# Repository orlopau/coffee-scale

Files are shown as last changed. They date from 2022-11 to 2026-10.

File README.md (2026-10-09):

# Coffee-Scale




---

This project contains the schematics, code and 3D models for a coffee scale based on an ESP32.

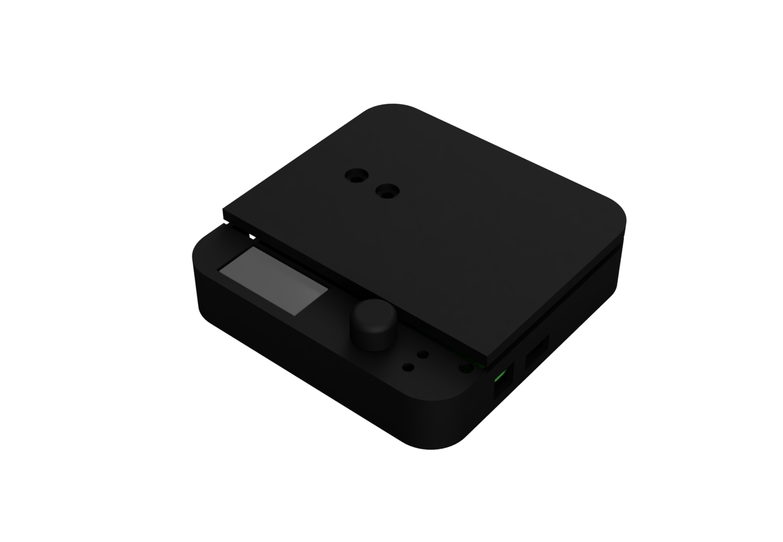
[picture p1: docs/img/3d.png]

 
## Features
* OTA updates via WiFi
* Recipe-based brewing
* Auto averaging of weight values: more values are used to determine weight when weight is relatively constant
* Brew timer
* USB-C charging
* Interchangeable Load Cell
* 3D-printable case
* Bluetooth and Wi-Fi connectivity

## Recipe-Based Brewing
The scale can be used to brew coffee using a step-by-step recipe. 
The recipe is stored on the scale, and can be adjusted while brewing.

Possible adjustments include:
- Changing the amount of coffee
- Changing the brew ratio
- Other adjustments based on the chosen recipe

## Development: Updating From Your Computer
During development, the scale can install a build straight from your computer over Wi-Fi, without USB and without a GitHub release.

1. In `code/`, run `pio run -t serve`. This builds the firmware and serves it on your network. It is found by the scale via mDNS, so your computer's IP does not matter. The first run installs the Python package `zeroconf`.
2. Hold the button while switching on the scale to open the updater. It connects to the Wi-Fi saved in the updater.
3. On the language screen, **long-press** the button instead of clicking. The scale searches for your computer and installs the build.

The server keeps running, so for the next build repeat steps 2 and 3 (`pio run -t serve` rebuilds when restarted). If the scale already runs the served build, it shows "No update available". Your computer and the scale must be on the same network, and the firewall must allow incoming connections for the server.

## Development: Emulator
The emulator runs the firmware on your computer, in a window that shows the scale's display. It needs SDL2 (`sudo apt install libsdl2-dev` on Debian/Ubuntu).

```
cd code
pio run -e emulator -t exec
```

With `COMPILE_LANG=de` in front, it runs in German. The load cell is simulated, and the keyboard replaces the encoder:

| Key | Action |
|---|---|
| Left / Right | turn the encoder |
| Enter, Space | press the encoder, hold for a long press |
| Up / Down | put 1 g on the scale or take it off, with Shift 0.1 g |
| PageUp / PageDown | 10 g on or off |
| Home | 100 g, e.g. for the calibration |
| 0, Backspace | clear the scale |
| F | pour on/off, 2 g/s |
| S | espresso shot: 6 s pre-infusion, then about 38 g in 33 s |
| N | noise on/off |
| - / + | slower/faster time, up to 20x (1x while the button is held) |
| P | save a screenshot to the current directory |
| Esc, Q | quit |

The window title shows the weight on the scale. The frame around the display lights up while the buzzer sounds. Settings are kept in memory only, and the boot splash screen and the updater only run on the device.

## Development: Screenshot Tests
The native tests render every screen through u8g2, set up like the scale's display, and compare it with the reference images in `code/test/native/test_screenshots/screens/`. A screen that changes fails the tests, and its new image is written to `code/test/native/test_screenshots/failed/` (on GitHub, attached to the CI run as `failed-screenshots`).

After changing a screen on purpose, accept the new images and commit them with the change:

```
cd code
UPDATE_SCREENSHOTS=1 pio test -e native -f native/test_screenshots
```

The diff of the pull request then shows each changed screen before and after.

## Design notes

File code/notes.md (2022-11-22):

## Modules

* Display/Output
* RotaryEncoder/Input
* LoadCell
* Modes...

soldering k12
https://www.aliexpress.com/item/4000456148198.html?spm=a2g0o.cart.0.0.4b184ae4xzGph2&mp=1

tips:
D32, D24, D16, D12, KF, ILS

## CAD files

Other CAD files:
models/Knob.step
models/Scale.step

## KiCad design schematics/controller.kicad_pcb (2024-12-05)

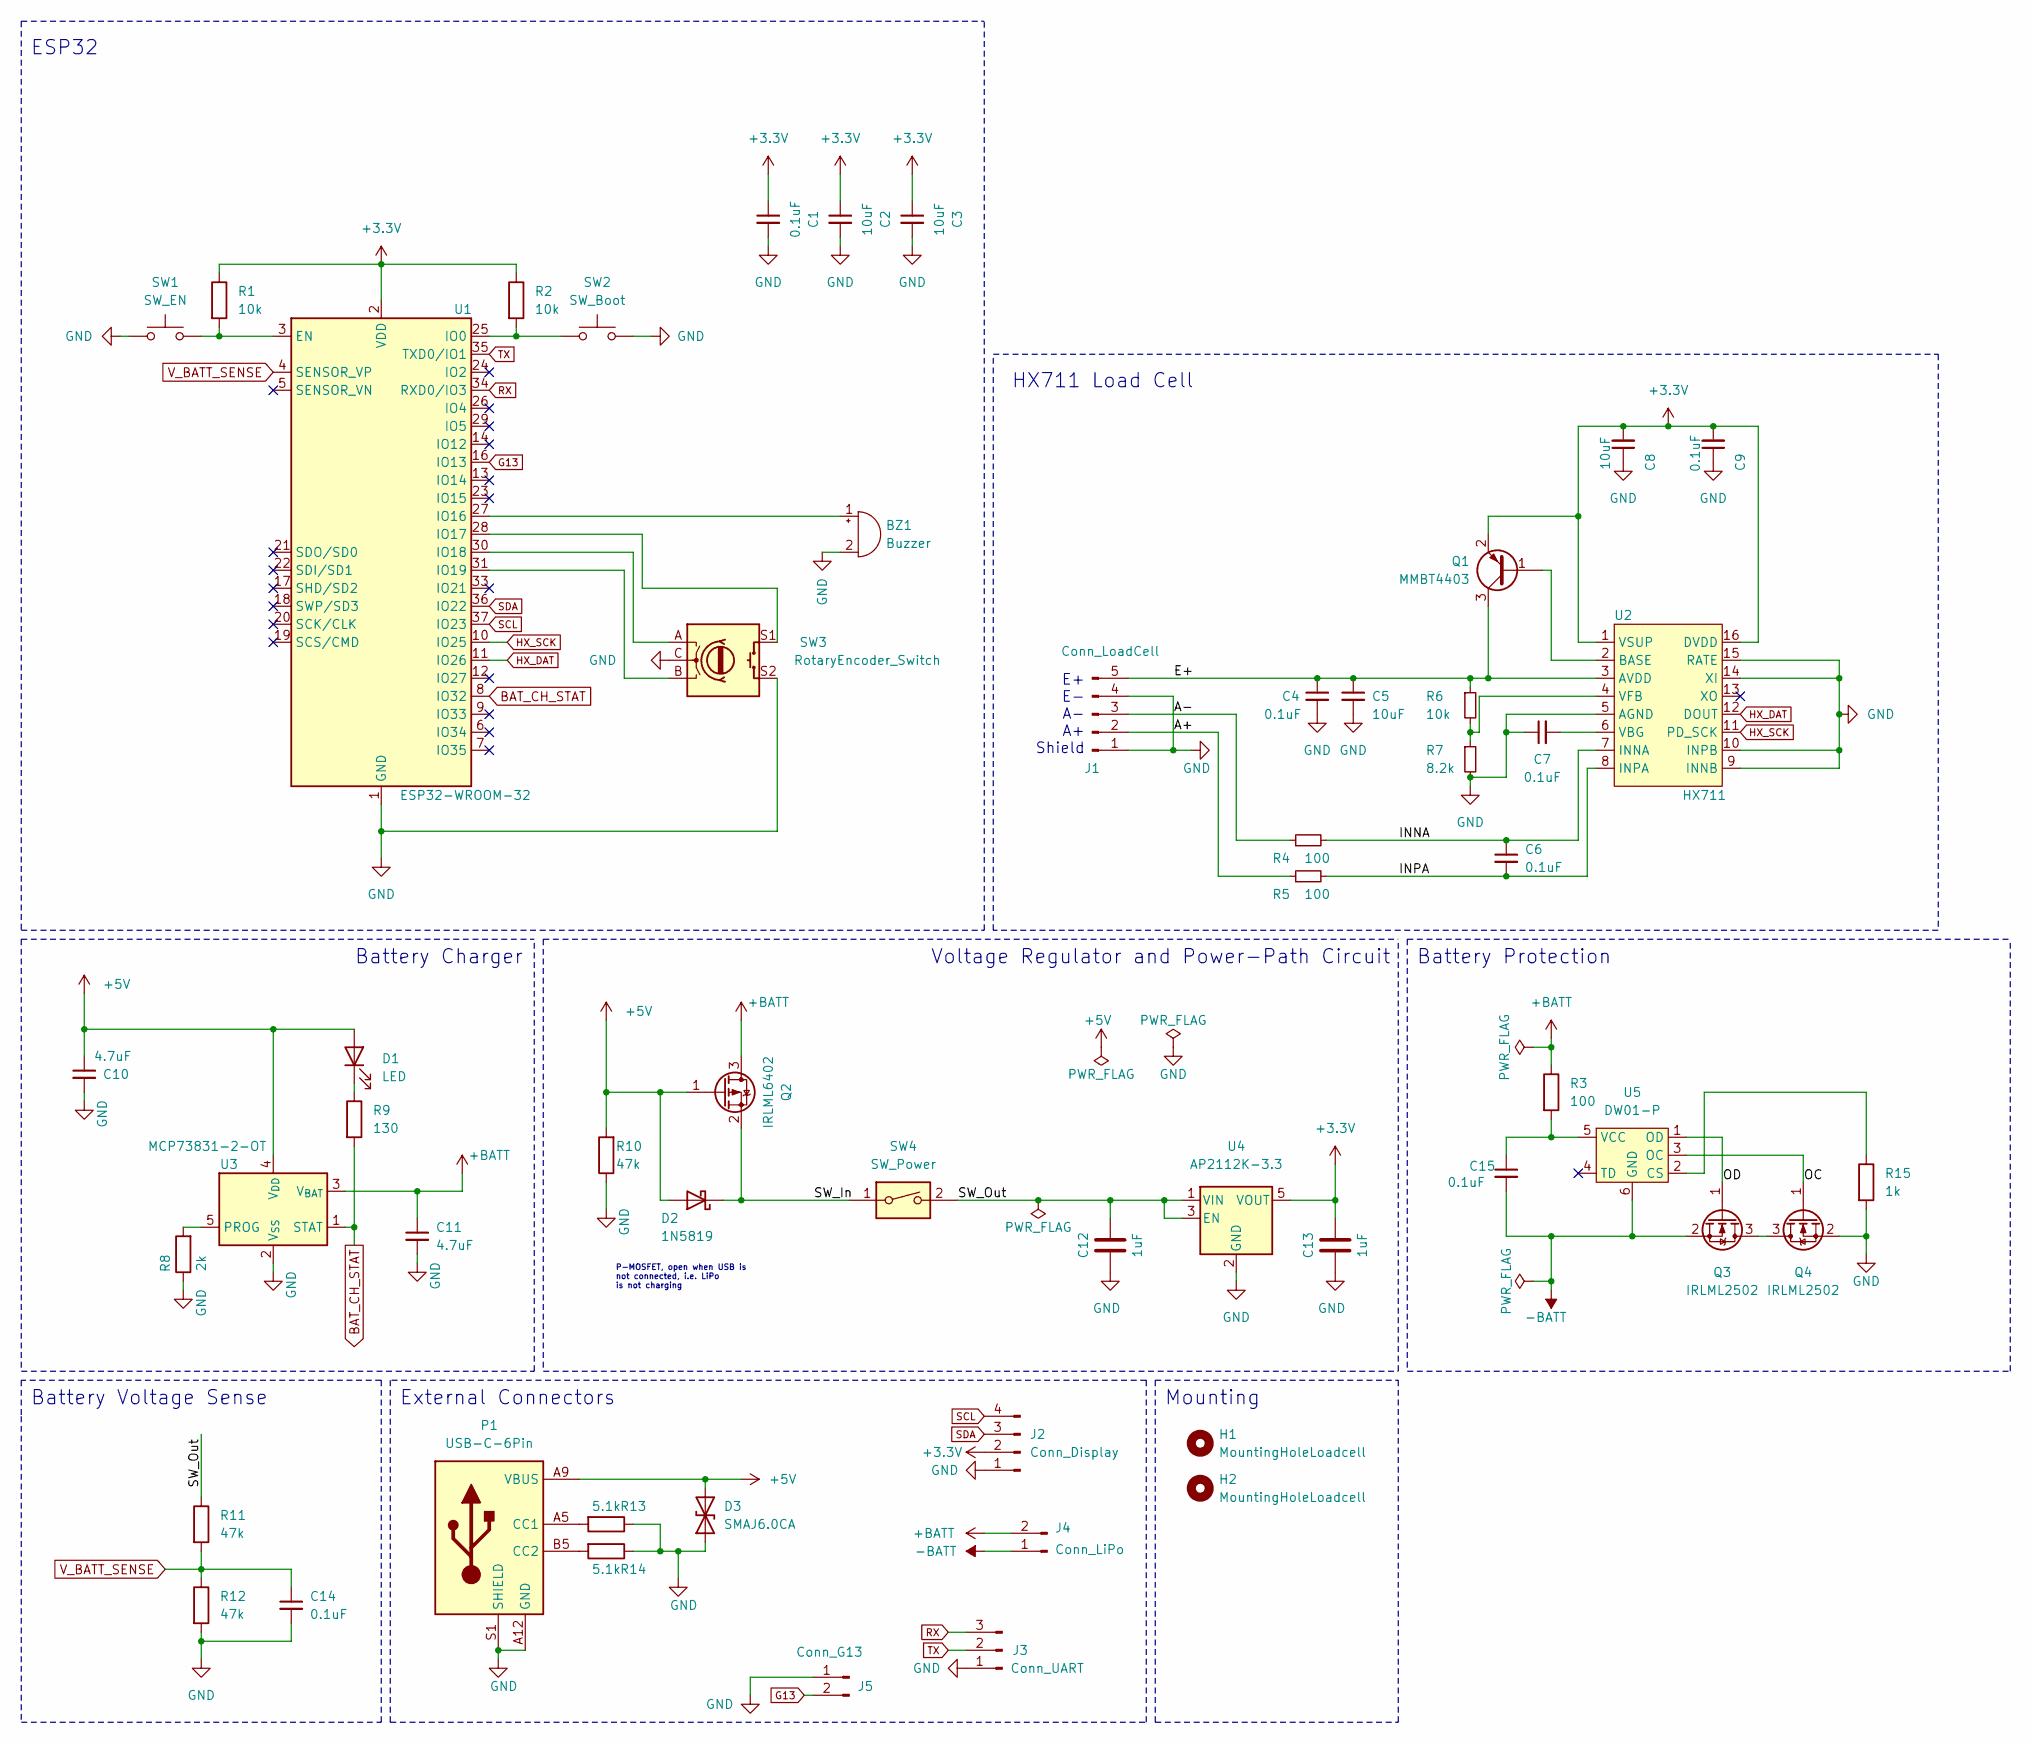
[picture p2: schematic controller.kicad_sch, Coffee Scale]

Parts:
BZ1: Buzzer; Buzzer_12x9.5RM7.6
C1, C4, C6, C7, C9, C14, C15: 0.1uF; C_0603_1608Metric_Pad1.08x0.95mm_HandSolder; LCSC C14663
C2, C3, C5, C8: 10uF; C_1206_3216Metric; LCSC C13585
C10, C11: 4.7uF; C_0805_2012Metric; LCSC C1779
C12, C13: 1uF; C_0805_2012Metric; LCSC C28323
D1: LED; LED_1206_3216Metric; LCSC C125086
D2: 1N5819; D_SMA_Handsoldering
D3: SMAJ6.0CA; D_SMA
H1, H2: MountingHoleLoadcell; MountingHole_5.3mm_M5_ISO7380
J1: Conn_LoadCell; SolderWire-0.5sqmm_1x05_P4.8mm_D0.9mm_OD2.3mm
J2: Conn_Display; SolderWire-0.5sqmm_1x04_P4.8mm_D0.9mm_OD2.3mm
J3: Conn_UART; PinHeader_1x03_P2.54mm_Horizontal
J4: Conn_LiPo; SolderWire-0.5sqmm_1x02_P4.8mm_D0.9mm_OD2.3mm
J5: Conn_G13; SolderWire-0.5sqmm_1x02_P4.8mm_D0.9mm_OD2.3mm
P1: USB-C-6Pin; USB_C_6Pin
Q1: MMBT4403; SOT-23; LCSC C78864
Q2: IRLML6402; SOT-23; LCSC C2593
Q3, Q4: IRLML2502; SOT-23; LCSC C5364308
R1, R2, R6: 10k; R_0603_1608Metric_Pad0.98x0.95mm_HandSolder; LCSC C25804
R3, R4, R5: 100; R_0603_1608Metric_Pad0.98x0.95mm_HandSolder; LCSC C22775
R7: 8.2k; R_0603_1608Metric_Pad0.98x0.95mm_HandSolder; LCSC C25981
R8: 2k; R_0603_1608Metric_Pad0.98x0.95mm_HandSolder; LCSC C22975
R9: 130; R_0603_1608Metric_Pad0.98x0.95mm_HandSolder; LCSC C22808
R10, R11, R12: 47k; R_0603_1608Metric_Pad0.98x0.95mm_HandSolder; LCSC C25819
R13, R14: 5.1k; R_0603_1608Metric_Pad0.98x0.95mm_HandSolder; LCSC C23186
R15: 1k; R_0603_1608Metric_Pad0.98x0.95mm_HandSolder; LCSC C21190
SW1: SW_EN; SW_PUSH_6mm_H5mm
SW2: SW_Boot; SW_PUSH_6mm_H5mm
SW3: RotaryEncoder_Switch; RotaryEncoder_Alps_EC11E-Switch_Vertical_H20mm
SW4: SW_Power; SolderWire-0.5sqmm_1x02_P4.8mm_D0.9mm_OD2.3mm
U1: ESP32-WROOM-32; LCSC C473012
U2: HX711; SOP-16_3.9x9.9mm_P1.27mm; LCSC C6705483
U3: MCP73831-2-OT; SOT-23-5; LCSC C424093
U4: AP2112K-3.3; SOT-23-5; LCSC C51118
U5: DW01-P; SOT-23-6_Handsoldering; LCSC C18164398

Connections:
+3.3V: C1.1, C2.1, C3.1, C8.2, C9.2, C13.2, J2.2, Q1.2 (E), R1.1, R2.1, U1.2 (VDD), U2.1 (VSUP), U2.16 (DVDD), U4.5 (VOUT)
+5V: C10.1, D1.2 (A), D2.2 (A), D3.2 (A2), P1.A9 (VBUS), P1.B9 (VBUS), Q2.1 (G), R10.2, U3.4 (V_{DD})
+BATT: C11.1, J4.2, Q2.3 (D), R3.1, U3.3 (V_{BAT})
-BATT: C15.2, J4.1, Q3.2 (S), U5.6 (GND)
/E+: C4.1, C5.1, J1.5, Q1.3 (C), R6.1, U2.3 (AVDD)
/INNA: C6.1, R4.2, U2.7 (INNA)
/INPA: C6.2, R5.2, U2.8 (INPA)
/OC: Q4.1 (G), U5.3 (OC)
/OD: Q3.1 (G), U5.1 (OD)
/SW_In: D2.1 (K), Q2.2 (S), SW4.1
/SW_Out: C12.2, R11.1, SW4.2, U4.1 (VIN), U4.3 (EN)
BAT_CH_STAT: R9.2, U1.8 (IO32), U3.1 (STAT)
G13: J5.2, U1.16 (IO13)
HX_DAT: U1.11 (IO26), U2.12 (DOUT)
HX_SCK: U1.10 (IO25), U2.11 (PD_SCK)
unnamed: BZ1.1 (+), U1.27 (IO16)
unnamed: D1.1 (K), R9.1
unnamed: P1.A5 (CC1), R13.2
unnamed: P1.B5 (CC2), R14.2
unnamed: Q1.1 (B), U2.2 (BASE)
unnamed: Q3.3 (D), Q4.3 (D)
unnamed: R1.2, SW1.2, U1.3 (EN)
unnamed: R2.2, SW2.1, U1.25 (IO0)
unnamed: SW3.S1, U1.28 (IO17)
unnamed: SW3.A, U1.30 (IO18)
unnamed: SW3.B, U1.31 (IO19)
unnamed: C7.2, U2.6 (VBG)
unnamed: R6.2, R7.1, U2.4 (VFB)
unnamed: R8.2, U3.5 (PROG)
unnamed: R15.1, U5.2 (CS)
unnamed: C15.1, R3.2, U5.5 (VCC)
RX: J3.3, U1.34 (RXD0/IO3)
SCL: J2.4, U1.37 (IO23)
SDA: J2.3, U1.36 (IO22)
TX: J3.2, U1.35 (TXD0/IO1)
V_BATT_SENSE: C14.1, R11.2, R12.1, U1.4 (SENSOR_VP)

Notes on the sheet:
ESP32
Battery Charger
HX711 Load Cell
E+ E- A- A+ Shield
Battery Protection
Mounting
External Connectors
Battery Voltage Sense
Voltage Regulator and Power-Path Circuit
P-MOSFET, open when USB is not connected, i.e. LiPo is not charging

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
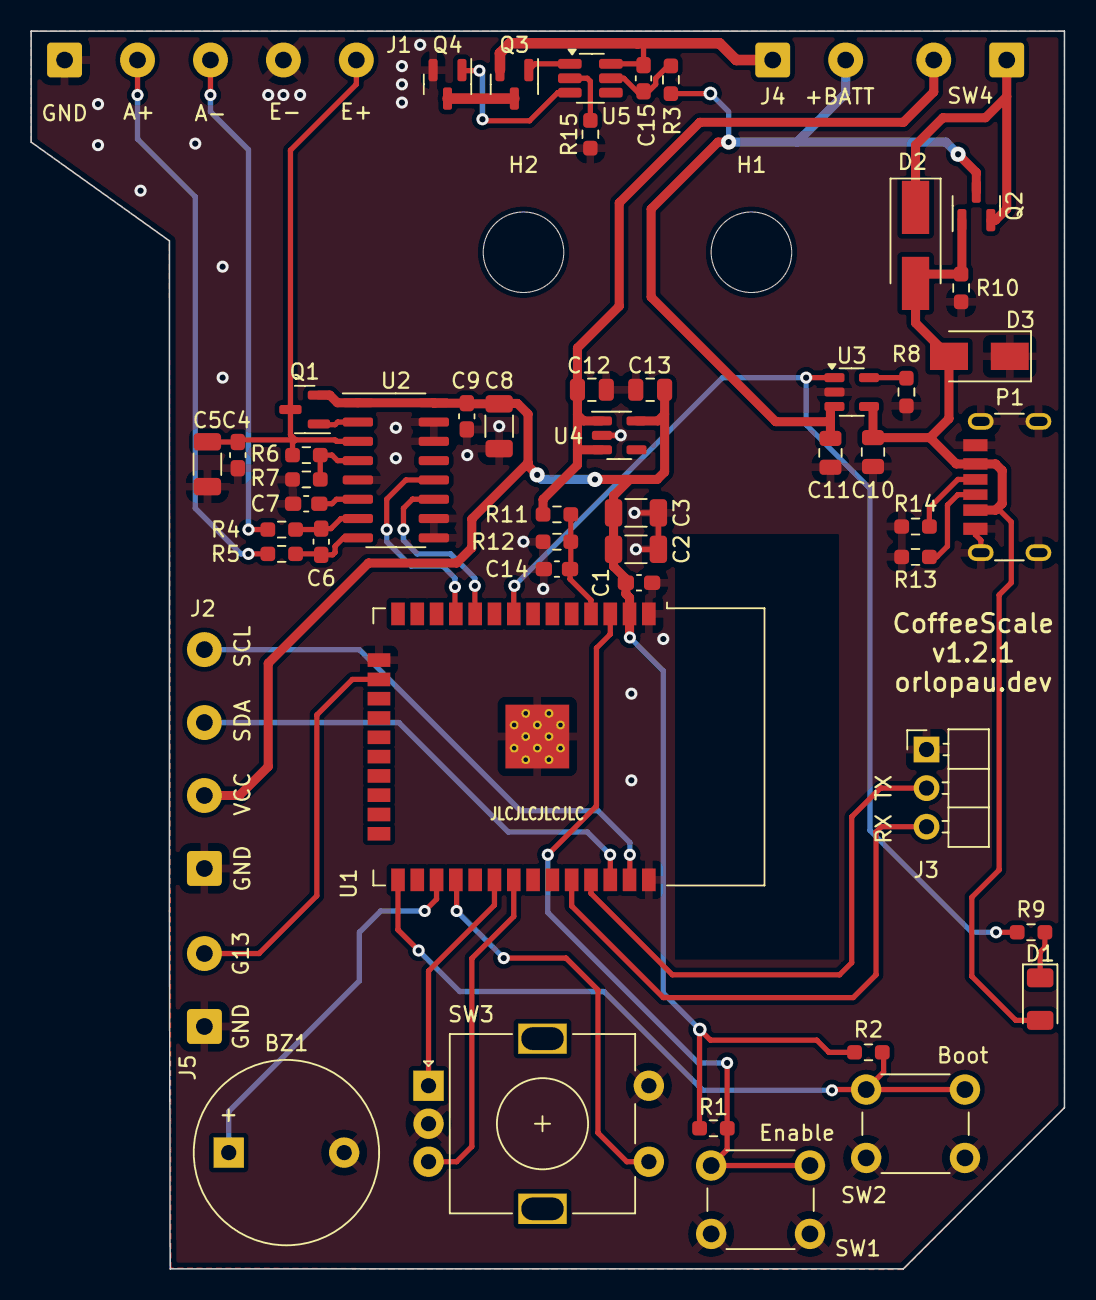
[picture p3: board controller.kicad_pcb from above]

Board: 2 copper layers, 68.0 x 81.5 mm, 55 parts (0 on the bottom side), 39 nets.

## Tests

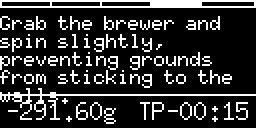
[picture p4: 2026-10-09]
code/test/native/test_screenshots/screens/recipe_brewing_3_pour_3.png

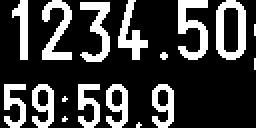
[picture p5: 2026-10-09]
code/test/native/test_screenshots/screens/scale_big.png

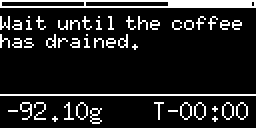
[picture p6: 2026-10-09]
code/test/native/test_screenshots/screens/recipe_brewing_4_pour_2.png

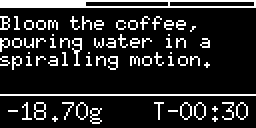
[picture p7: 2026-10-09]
code/test/native/test_screenshots/screens/recipe_brewing_4_pour_0.png

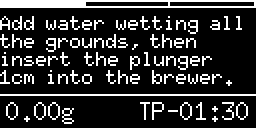
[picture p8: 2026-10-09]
code/test/native/test_screenshots/screens/recipe_brewing_pause.png

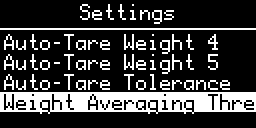
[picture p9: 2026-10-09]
code/test/native/test_screenshots/screens/settings_last.png

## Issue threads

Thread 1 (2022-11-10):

Buzzer is very quiet

orlopau, 2022-11-10:
Additional MOSFET to switch buzzer?
Use lower R value?

Closed 2022-12-08.

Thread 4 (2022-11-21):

PCB improvements

orlopau, 2022-11-21:
- [x] Add battery protection ic (S-8240A, DW01, AP9101C)
- [x] Add TVS diode
- [x] Add LiIon fuel gauge IC (discarded due to no availability of parts)
- [x] Add automatic boot mode change (automatic upload) (discarded, too many external pins)
- [x] Add RTS pin to pin header (see above)
- [x] Replace buzzer footprint
- [x] Tighter screw holes
- [x] More accessible buttons
- [ ] Route out GPIO pins (?) for later additions
- [ ] Realign Boot BTN with Rotary Encoder center

Closed 2022-12-14.

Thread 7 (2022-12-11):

Replaceable LiIon Battery

orlopau, 2022-12-11:

Closed 2023-01-05.

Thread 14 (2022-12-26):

AP9101 not auto-waking

orlopau, 2022-12-26:
After over-discharge protection triggers, bat GND and GND muste be shorted to activate the chip again. There is also an auto-wakeup version of this chip available.

orlopau, 2023-05-06:
Quickfix: Add a button to reset the chip? Maybe the exposed boot button can be used, or rotary encoder button?

orlopau, 2024-12-14:
Fixed in new HW revision pcb-v1.2.1

Closed 2024-12-14.

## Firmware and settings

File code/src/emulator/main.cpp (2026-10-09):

#ifdef EMULATOR

// The scale's firmware on a computer: runs the modes like on the device, in
// a window, with the keyboard as encoder and a simulated load cell.
//
//   pio run -e emulator -t exec

#define SDL_MAIN_HANDLED
#include <SDL.h>

#include <cstdio>
#include <fstream>
#include <string>

#include "emulator/emulator.h"
#include "battery.h"
#include "data/recipes.h"
#include "display.h"
#include "interface.h"
#include "loadcell.h"
#include "millis.h"
#include "mode_manager.h"
#include "modes/mode_calibrate.h"
#include "modes/mode_espresso.h"
#include "modes/mode_recipe.h"
#include "modes/mode_scale.h"
#include "modes/mode_settings.h"
#include "settings.h"
#include "stopwatch.h"
#include "weight_sensor.h"

// window pixels per display pixel, and the frame around the display
#define PIXEL_SIZE 4
#define BORDER 12
#define FRAME_MS 15
// liquid flowing onto the scale while pouring, in g/s
#define POUR_FLOW 2.0f

static const int SPEEDS[] = {1, 2, 5, 10, 20};
static const int SPEED_COUNT = sizeof(SPEEDS) / sizeof(SPEEDS[0]);

static const char *HELP = "Coffee Scale emulator\n"
                          "  Left/Right       turn the encoder\n"
                          "  Enter, Space     press the encoder (hold for a long press)\n"
                          "  Up/Down          put 1 g on the scale or take it off, with Shift 0.1 g\n"
                          "  PageUp/PageDown  10 g, Home 100 g (e.g. for calibration)\n"
                          "  0, Backspace     clear the scale\n"
                          "  F                pour on/off (2 g/s)\n"
                          "  S                espresso shot (6 s pre-infusion, about 38 g in 33 s)\n"
                          "  N                noise on/off\n"
                          "  - +              slower/faster time, up to 20x (1x while the button is held)\n"
                          "  P                save a screenshot\n"
                          "  Esc, Q           quit\n";

static DefaultWeightSensor weightSensor;
static Stopwatch stopwatch;

static void saveScale(float scale)
{
    printf("New scale: %f\n", scale);
    weightSensor.setScale(scale);
}

/** As the device's setup() does, with the scale calibrated already. */
static void setup()
{
    Interface::begin();
    Battery::init();
    Display::begin();
    weightSensor.begin();

    const float scale = 1 / SimulatedScale::COUNTS_PER_GRAM;
    weightSensor.setScale(scale);
    const float delta = fabs(Settings::getFloat(Settings::floatSettings[Settings::AVERAGING_DELTA]) / scale);
    weightSensor.setAutoAveraging(delta, 64);

    // tare after 32 samples
    for (int i = 0; i < 32;)
    {
        sleep_for(1);
        weightSensor.update();
        if (weightSensor.isNewWeight())
        {
            i++;
        }
    }
    weightSensor.tare();
}

/** One pass of the device's loop(). */
static void loop(ModeManager &modeManager)
{
    Interface::update();
    weightSensor.update();
    modeManager.update();
}

static void saveScreenshot()
{
    static int count = 0;
    std::string path;
    // the next free name, so earlier screenshots are kept
    do
    {
        path = "screenshot-" + std::to_string(++count) + ".png";
    } while (std::ifstream(path).good());
    std::ofstream(path, std::ios::binary) << Emulator::display().png(PIXEL_SIZE);
    printf("Saved %s\n", path.c_str());
}

static void updateTitle(SDL_Window *window, int speed)
{
    char title[128];
    int length = snprintf(title, sizeof(title), "Coffee Scale - %.1f g on the scale", Emulator::scale.getWeight());
    if (Emulator::scale.isShotRunning())
    {
        length += snprintf(title + length, sizeof(title) - length, " - shot, %.1f g/s", Emulator::scale.getFlow());
    }
    else if (Emulator::scale.getFlow() != 0)
    {
        length += snprintf(title + length, sizeof(title) - length, " - pouring %.1f g/s", Emulator::scale.getFlow());
    }
    if (Emulator::scale.hasNoise())
    {
        length += snprintf(title + length, sizeof(title) - length, " - noise");
    }
    if (speed != 1)
    {
        snprintf(title + length, sizeof(title) - length, " - %dx", speed);
    }

    static std::string shown;
    if (shown != title)
    {
        SDL_SetWindowTitle(window, title);
        shown = title;
    }
}

static void draw(SDL_Renderer *renderer, SDL_Texture *texture)
{
    VirtualDisplay &display = Emulator::display();
    uint32_t *pixels;
    int pitch;
    SDL_LockTexture(texture, nullptr, (void **)&pixels, &pitch);
    for (int y = 0; y < display.height(); y++)
    {
        for (int x = 0; x < display.width(); x++)
        {
            pixels[y * pitch / 4 + x] = display.pixel(x, y) ? 0xFFE8F0FF : 0xFF000000;
        }
    }
    SDL_UnlockTexture(texture);

    // the frame lights up while the buzzer sounds
    if (Emulator::isBuzzing())
    {
        SDL_SetRenderDrawColor(renderer, 0xF0, 0xA0, 0x20, 0xFF);
    }
    else
    {
        SDL_SetRenderDrawColor(renderer, 0x30, 0x30, 0x30, 0xFF);
    }
    SDL_RenderClear(renderer);
    const SDL_Rect screen = {BORDER, BORDER, display.width() * PIXEL_SIZE, display.height() * PIXEL_SIZE};
    SDL_RenderCopy(renderer, texture, nullptr, &screen);
    SDL_RenderPresent(renderer);
}

/** Handles a key, returns false to quit. */
static bool handleKey(const SDL_KeyboardEvent &key, int &speedIndex)
{
    const bool down = key.type == SDL_KEYDOWN;
    const bool shift = key.keysym.mod & KMOD_SHIFT;
    SimulatedScale &scale = Emulator::scale;

    switch (key.keysym.sym)
    {
    case SDLK_RETURN:
    case SDLK_KP_ENTER:
    case SDLK_SPACE:
        Emulator::setButtonPressed(down);
        return true;
    case SDLK_ESCAPE:
    case SDLK_q:
        return !down;
    }

    if (!down)
    {
        return true;
    }

    // keys that may repeat while held
    switch (key.keysym.sym)
    {
    case SDLK_RIGHT:
        Emulator::turnEncoder(1);
        break;
    case SDLK_LEFT:
        Emulator::turnEncoder(-1);
        break;
    case SDLK_UP:
        scale.addWeight(shift ? 0.1f : 1);
        break;
    case SDLK_DOWN:
        scale.addWeight(shift ? -0.1f : -1);
        break;
    case SDLK_PAGEUP:
        scale.addWeight(10);
        break;
    case SDLK_PAGEDOWN:
        scale.addWeight(-10);
        break;
    case SDLK_HOME:
        scale.addWeight(100);
        break;
    }

    if (key.repeat)
    {
        return true;
    }

    switch (key.keysym.sym)
    {
    case SDLK_0:
    case SDLK_KP_0:
    case SDLK_BACKSPACE:
        scale.setWeight(0);
        break;
    case SDLK_f:
        scale.setFlow(scale.getFlow() == 0 || scale.isShotRunning() ? POUR_FLOW : 0);
        break;
    case SDLK_s:
        scale.startShot();
        break;
    case SDLK_n:
        scale.setNoise(!scale.hasNoise());
        break;
    case SDLK_MINUS:
    case SDLK_KP_MINUS:
        speedIndex = speedIndex > 0 ? speedIndex - 1 : 0;
        break;
    case SDLK_PLUS:
    case SDLK_EQUALS: // + without Shift on US keyboards
    case SDLK_KP_PLUS:
        speedIndex = speedIndex < SPEED_COUNT - 1 ? speedIndex + 1 : SPEED_COUNT - 1;
        break;
    case SDLK_p:
        saveScreenshot();
        break;
    }
    return true;
}

int main(int argc, char **argv)
{
    // line by line, also when the output goes to a pipe, e.g. with pio run -t exec
    setvbuf(stdout, nullptr, _IOLBF, 0);
    setup();

    ModeScale modeDefault(weightSensor, stopwatch);
    ModeEspresso modeEspresso(weightSensor, stopwatch);
    ModeCalibration modeCalibration(stopwatch, saveScale);
    ModeSettings modeSettings;
    ModeRecipes modeRecipes(weightSensor, RECIPES, RECIPE_COUNT);
    Mode *modes[] = {&modeDefault, &modeRecipes, &modeEspresso, &modeCalibration, &modeSettings};
    ModeManager modeManager(modes, 5, Display::canvas());
    modeManager.begin();

    SDL_SetMainReady();
    if (SDL_Init(SDL_INIT_VIDEO) != 0)
    {
        fprintf(stderr, "SDL_Init failed: %s\n", SDL_GetError());
        return 1;
    }
    VirtualDisplay &display = Emulator::display();
    SDL_Window *window = SDL_CreateWindow("Coffee Scale", SDL_WINDOWPOS_CENTERED, SDL_WINDOWPOS_CENTERED,
                                          display.width() * PIXEL_SIZE + 2 * BORDER,
                                          display.height() * PIXEL_SIZE + 2 * BORDER, 0);
    SDL_Renderer *renderer = window ? SDL_CreateRenderer(window, -1, 0) : nullptr;
    SDL_Texture *texture = renderer ? SDL_CreateTexture(renderer, SDL_PIXELFORMAT_ARGB8888, SDL_TEXTUREACCESS_STREAMING,
                                                        display.width(), display.height())
                                    : nullptr;
    if (texture == nullptr)
    {
        fprintf(stderr, "Creating the window failed: %s\n", SDL_GetError());
        return 1;
    }
    printf("%s", HELP);

    int speedIndex = 0;
    Uint64 lastRealTime = SDL_GetTicks64();
    Uint64 pendingMs = 0;
    bool running = true;
    while (running)
    {
        SDL_Event event;
        while (running && SDL_PollEvent(&event))
        {
            if (event.type == SDL_QUIT)
            {
                running = false;
            }
            else if (event.type == SDL_KEYDOWN || event.type == SDL_KEYUP)
            {
                running = handleKey(event.key, speedIndex);
            }
        }

        // The virtual clock catches up with real time, times the speed, in
        // steps of 1 ms. While the button is held, time runs at normal speed,
        // so a long press takes as long as on the device.
        const Uint64 realTime = SDL_GetTicks64();
        const Uint64 elapsed = SDL_min(realTime - lastRealTime, 100); // e.g. after the window was dragged
        lastRealTime = realTime;
        const int speed = Emulator::isButtonPressed() ? 1 : SPEEDS[speedIndex];
        pendingMs += elapsed * speed;
        for (; pendingMs > 0; pendingMs--)
        {
            sleep_for(1);
            Emulator::scale.update();
            loop(modeManager);
        }

        updateTitle(window, SPEEDS[speedIndex]);
        draw(renderer, texture);
        SDL_Delay(FRAME_MS);
    }

    SDL_DestroyTexture(texture);
    SDL_DestroyRenderer(renderer);
    SDL_DestroyWindow(window);
    SDL_Quit();
    return 0;
}

#endif

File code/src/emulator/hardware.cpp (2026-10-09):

#ifdef EMULATOR

#include <array>
#include <cmath>

#include "emulator/emulator.h"
#include "battery.h"
#include "button.h"
#include "display.h"
#include "interface.h"
#include "loadcell.h"
#include "millis.h"
#include "settings.h"

// A click shorter than the button's debounce time would get lost, e.g. when
// a key is pressed and released between two loops.
#define MIN_PRESS_MS 100

namespace Emulator
{
    SimulatedScale scale;

    static long encoderPosition = 0;
    static bool buttonDown = false;
    static unsigned long pressTime = 0;
    static Button encoderButton;
    static unsigned long buzzerEndTime = 0;

    void turnEncoder(int detents) { encoderPosition += detents; }

    void setButtonPressed(bool pressed)
    {
        if (pressed && !buttonDown)
        {
            pressTime = now();
        }
        buttonDown = pressed;
    }

    bool isButtonPressed() { return buttonDown || now() - pressTime < MIN_PRESS_MS; }

    bool isBuzzing() { return now() < buzzerEndTime; }

    VirtualDisplay &display()
    {
        static VirtualDisplay display;
        return display;
    }
}

namespace Interface
{
    // like the RotaryEncoder library: the direction since the last call
    static long lastDirectionPosition = 0;

    void begin() {}

    void update() { Emulator::encoderButton.update(Emulator::isButtonPressed()); }

    EncoderDirection getEncoderDirection()
    {
        const long position = Emulator::encoderPosition;
        const long last = lastDirectionPosition;
        lastDirectionPosition = position;
        if (position > last)
        {
            return EncoderDirection::CW;
        }
        if (position < last)
        {
            return EncoderDirection::CCW;
        }
        return EncoderDirection::NONE;
    }

    long getEncoderTicks() { return Emulator::encoderPosition; }

    void setEncoderTicks(long ticks) { Emulator::encoderPosition = ticks; }

    void resetEncoderTicks() { Emulator::encoderPosition = 0; }

    ClickType consumeEncoderClick() { return Emulator::encoderButton.consumeClickType(); }

    ClickType getEncoderClick() { return Emulator::encoderButton.getClickType(); }

    bool isEncoderPressed() { return Emulator::encoderButton.isPressed(); }

    void buzzerTone(unsigned int durationMs) { Emulator::buzzerEndTime = now() + durationMs; }
}

namespace LoadCell
{
    void begin() {}

    bool isReady() { return Emulator::scale.isReady(); }

    long read() { return Emulator::scale.read(); }
}

namespace Display
{
    void begin() {}

    Canvas &canvas() { return Emulator::display().canvas(); }

    // The splash screen draws with u8g2's Arduino API, which needs the device.
    void drawOpener() {}
}

namespace Battery
{
    void init() {}

    float getVoltage() { return 3.95f; }

    float getPercentage() { return 75; }

    bool isCharging() { return false; }
}

// Kept in memory only, every start begins with the defaults.
namespace Settings
{
    static std::array<float, FLOAT_SETTING_NUM> values = [] {
        std::array<float, FLOAT_SETTING_NUM> v;
        v.fill(NAN);
        return v;
    }();

    float getFloat(FloatSetting s) { return std::isnan(values[s.id]) ? s.def : values[s.id]; }

    void setFloat(FloatSetting s, float value) { values[s.id] = value; }

    void commit() {}
}

#endif

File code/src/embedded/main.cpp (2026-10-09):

#if !defined(PIO_UNIT_TESTING) && !defined(NATIVE)

#include <Arduino.h>
#include <EEPROM.h>

#include "constants.h"
#include "data/recipes.h"
#include "loadcell.h"
#include "mode.h"
#include "mode_manager.h"
#include "modes/mode_scale.h"
#include "modes/mode_espresso.h"
#include "modes/mode_calibrate.h"
#include "modes/mode_recipe.h"
#include "modes/mode_settings.h"
#include "display.h"
#include "update.h"
#include "interface.h"
#include "battery.h"

#define AVERAGING_LOOPS 100

#define TAG "MAIN"

DefaultWeightSensor weightSensor;
Stopwatch stopwatch;

void saveScale(float scale)
{
  ESP_LOGI(TAG, "New scale: %f", scale);
  ESP_LOGI(TAG, "Saving scale to EEPROM...");
  EEPROM.put(EEPROM_ADDR_SCALE, scale);
  EEPROM.commit();
  weightSensor.setScale(scale);
}

ModeScale modeDefault(weightSensor, stopwatch);
ModeEspresso modeEspresso(weightSensor, stopwatch);
ModeCalibration modeCalibration(stopwatch, saveScale);
ModeSettings modeSettings;
ModeRecipes modeRecipes(weightSensor, RECIPES, RECIPE_COUNT);
Mode *modes[] = {&modeDefault, &modeRecipes, &modeEspresso, &modeCalibration, &modeSettings};
ModeManager modeManager(modes, 5, Display::canvas());

Interface::EncoderDirection encoderDirection;

void IRAM_ATTR isr_input()
{
  Interface::update();
}

void setup()
{
  Serial.begin(115200);
  ESP_LOGI(TAG, "CoffeeScale starting up...");

  EEPROM.begin(2048);
  btStop();

  //////// INTERFACE //////
  Interface::begin();

  //////// BATTERY ////////
  Battery::init();

  //////// DISPLAY ////////
  Display::begin();
  Display::drawOpener();

  //////// WEIGHT SENSOR ////////
  LoadCell::begin();
  weightSensor.begin();

  float scale;
  EEPROM.get(EEPROM_ADDR_SCALE, scale);
  if (isnan(scale))
  {
      scale = 1.0f;
  }

  ESP_LOGI(TAG, "Existing scale: %f", scale);
  weightSensor.setScale(scale);


  float delta = abs(Settings::getFloat(Settings::floatSettings[Settings::AVERAGING_DELTA]) / scale);
  weightSensor.setAutoAveraging(delta, 64);
  ESP_LOGI(TAG, "Auto averaging delta: %f", delta);

  // tare after 32 samples
  ESP_LOGI(TAG, "Taring...");
  for (int i = 0; i < 32;)
  {
      weightSensor.update();
      if (weightSensor.isNewWeight())
      {
          i++;
      }
  }
  weightSensor.tare();
  ESP_LOGI(TAG, "Tared!");

  //////// INTERRUPTS ////////
  attachInterrupt(PIN_ENC_A, isr_input, CHANGE);
  attachInterrupt(PIN_ENC_B, isr_input, CHANGE);
  attachInterrupt(PIN_ENC_BTN, isr_input, CHANGE);

  //////// UPDATES ////////
  if (digitalRead(PIN_UPDATE_FIRMWARE) == LOW)
  {
      Updater::update_firmware();
  }

  /// MODE MANAGER ////
  modeManager.begin();

  ESP_LOGI(TAG, "Setup finished!");
}

#ifdef PERF
unsigned int loops = 0;
unsigned long lastTime = millis();
#endif

void loop()
{
  Interface::update();
  weightSensor.update();
  modeManager.update();

#ifdef PERF
  if (loops >= AVERAGING_LOOPS)
  {
    ESP_LOGI(TAG, "Loop time: %lu", (millis() - lastTime) / loops);
    loops = 0;
    lastTime = millis();
  }
  loops++;
#endif
}

#endif

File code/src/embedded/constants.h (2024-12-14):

#ifndef NATIVE

#pragma once

// Pin definitions
#define PIN_BOOT 0

#define PIN_I2C_SDA 22
#define PIN_I2C_SCL 23

#define PIN_BUZZER 16

#define PIN_BAT_CHARGE_STATUS 32

#define PIN_HX711_SCK 25
#define PIN_HX711_DAT 26

#define PIN_ENC_A 18
#define PIN_ENC_B 19
#define PIN_ENC_BTN 17

#define PIN_BAT_ADC 36

// Other constants
#define BAT_V_MULTIPLIER 2.0f
#define BAT_V_MIN 3.2f
#define BAT_V_MAX 4.2f

#define ADC_OFFSET 0.04f

// EEPROM addresses
#define EEPROM_ADDR_SCALE 0
#define EEPROM_ADDR_FLOAT_SETTINGS 10

// BUTTONS
#define PIN_UPDATE_FIRMWARE PIN_ENC_BTN

// UPDATE
#define UPDATE_URL "https://github.com/orlopau/coffee-scale/releases/latest/download/firmware%s.bin"

#ifndef FIRMWARE_VERSION
#define FIRMWARE_VERSION "0.0.0"
#endif

#endif

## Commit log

2022-11-02 Added pcb design
    [controller.kicad_pcb, controller.kicad_sch]
2022-11-07 Updated pcb
    [controller.kicad_pcb]
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2022-11-26 Fixed tests for mode manager and mode default
    [main.cpp]
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2022-12-01 Reworked mode switcher
2022-12-01 Fixed segfault, missing null termiantion
    [main.cpp]
2022-12-01 Fixed mode manager
    Mode manager called the update function of the next chosen mode in the same tick.
    This lead to the single click which is needed to select a new mode being propagated
    instantly to the new mode.
    [main.cpp]
2022-12-02 Updated voltage divider for hx711 in schematic
    [controller.kicad_pcb, controller.kicad_sch]
2022-12-06 Fixed ratio of pours not being adjusted
    [main.cpp]
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2022-12-06 Fixed test for loadcell tare
    Was not adjusted to taring via rotating the encoder
    [main.cpp]
2022-12-06 Added buzzer tone function
    [main.cpp]
2022-12-14 Updated schematic to v1.1.0
    * Added TVS diode for USB connector
    * Added active buzzer instead of passive piezo buzzer
    * Added battery protection IC
    * Changed location of enable button, enabling the mounting of a button which is visible externally
    [controller.kicad_pcb, controller.kicad_sch]
2022-12-14 Changed circular mounting holes to eliptical for rotary encoder
    [controller.kicad_pcb, controller.kicad_sch]
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2022-12-21 Fixed pause time not being shown when pour time is zero
    When autoStart was not disabled for a pour, and the
    pourTime for that pour was 0, 0 would be displayed instead
    of the pauseTime.
    [main.cpp]
2022-12-27 Fixed wrong scaling for ADC values
    [adc_battery.cpp, main.cpp]
2022-12-27 Fixed brewing step showing only the weight of the current pour
    [main.cpp]
2023-01-05 Fixed calibration mode
2023-01-05 Fixed unstable debounce test
    [main.cpp]
2023-01-09 Fixed update not using HTTPS
    [constants.h]
2023-01-09 Fixed calibration not waiting for laodcell readiness
    [main.cpp]
2023-01-09 Added long click detection when button is kept pressed
    Previously for detecting a long click the button must have been released.
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2023-01-10 Fixed flickering battery display by introducing an update interval
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2023-01-10 Fixed voltage not showing when internal millis was less than interval
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2023-04-03 Fixed a bug when setting a new ratio, advancing to the weight config step and then returning.
    In this case the ratio was not reset correctly.
    Closes #25.
    [main.cpp, step_config_ratio.cpp]
2023-05-06 Feature: User can force progress a pour, even when it has not finished
    Fixed #24
    [main.cpp]
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2023-05-06 Bugfix: Auto averaging did not work with negative scales
    [main.cpp]
2023-11-26 Added *.step models for scale and knob
    [Knob.step, Scale.step]
2024-12-05 Changed lipo protection IC to DW01, added LCSC part numbers
    [controller.kicad_pcb, controller.kicad_sch]
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2024-12-14 Added config parameter for auto tare tolerance
    [localization.h, main.cpp]
2026-10-09 Add Canvas abstraction, capped render loop, migrate espresso mode
    Screens no longer need to live in the Display namespace. Modes can now
    draw themselves on a small Canvas interface, and the ModeManager renders
    them at most every 50 ms instead of on every loop.
    - Canvas interface (include/canvas.h) with a u8g2 backend that only sends
    a frame over I2C when it changed (plus a refresh once per second).
    - Reusable widgets (src/ui/widgets): centered text, title line, segment
    bar, progress bar, word wrap. Legacy screens use them too and render
    pixel-identically to before.
    - Mode::render(Canvas&) / rendersToCanvas(); legacy modes keep drawing in
    update() until they are migrated.
    - Espresso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
    [main.cpp]
2026-10-09 Add dev updates from a computer via mDNS
    The firmware updater can now install a build served from the developer's
    computer instead of the latest GitHub release, for quick iteration
    without USB.
    - `pio run -t serve` builds the firmware and serves it over HTTP,
    announced via mDNS as _coffeescale-fw._tcp (scripts/serve_firmware.py,
    installs zeroconf on first use).
    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
2026-10-09 Pin the official espressif32 platform
    An unpinned `espressif32` can resolve to another installed platform of the
    same name, such as the pioarduino fork with Arduino core 3.x, which
    AutoConnect/PageBuilder do not compile against. Pin
    platformio/espressif32@7.1.3 so local builds match the release builds.
2026-10-09 Fix the German Wi-Fi setup text on the updater
    Display::text drew with drawStr, which treats text as Latin-1, so
    "wählen" showed as "wÃ¤hlen". Draw it as UTF-8 like the other screens.
    The German string also had "\v" instead of "\n" before "verbinden",
    which merged two lines and pushed text off the screen.
    [localization.h]
2026-10-09 Show the saved scale after calibration
    The result screen printed a local variable that was only set in the
    previous update(), so it showed an undefined value. Keep the scale as
    a member.
2026-10-09 Move all remaining screens into the modes' render()
    Every screen now draws through the Canvas: scale mode, all recipe steps,
    calibration, settings, the mode switcher (drawn by ModeManager) and the
    updater screens. Display keeps only begin(), canvas() and the boot
    splash. Mode::render() is now required and rendersToCanvas() is gone.
    - Canvas: fonts for the remaining screens (SmallMedium, Mono13/18/20,
    Battery) and drawGlyph() for the rotated battery icon.
    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
2026-10-09 Run native builds on a virtual clock
    now() in native builds returns a virtual time that only moves through
    sleep_for() and the new set_now(), instead of the system clock. Tests that
    depend on timing no longer wait in real time and get exact results, and the
    upcoming screenshot tests and emulator can control time.
    [main.cpp]
2026-10-09 Build U8g2Canvas natively
    The canvas only uses the u8g2 C API, so it moves from src/embedded to src/ui
    and the native env gets u8g2 too. Both envs use the same exact u8g2 version,
    so native renders match the device.
2026-10-09 Draw the updater's screens in src/ui
    The updater only runs on the device, so its screens move to UpdaterScreens
    where native tests can render them. The frames are unchanged.
2026-10-09 Add screenshot tests of every screen
    test_screenshots renders each screen through u8g2, set up like the scale's
    display, and compares it with a PNG in screens/. Changed screens fail the
    test and are written to failed/, which CI uploads. UPDATE_SCREENSHOTS=1
    accepts the new images, so pull requests show screen changes as image diffs.
    The battery mock is now settable, for the mode switcher's battery states.
    [main.cpp]
2026-10-09 Simulate the load cell for native builds
    SimulatedScale turns grams into raw HX711 readings at 80 samples per second,
    on the virtual clock. Weight can be put on and taken off, liquid can flow at
    a constant rate, and an espresso shot follows a typical flow profile, with
    optional noise.
    [main.cpp]
2026-10-09 Add an emulator of the scale
    pio run -e emulator -t exec runs the firmware's modes in an SDL window: the
    arrow keys and Enter replace the encoder, other keys put weight on the
    simulated scale, pour, or start an espresso shot, and time can run up to 20x
    faster. src/emulator has the emulator's Interface, LoadCell, Display,
    Battery and Settings, guarded by EMULATOR like src/embedded is for the
    device. CI builds it, so it does not break unnoticed.
    [hardware.cpp, main.cpp]
2026-10-09 Remove the old display dev main
    main_display.cpp no longer compiled, the emulator replaces it.
    [main.cpp]
2026-10-09 Simulate the HX711 at 10 samples per second
    The scale's HX711 runs at 10 samples per second, not 80.
2026-10-09 Print the emulator's output line by line
    With pio run -t exec, the output goes to a pipe, where it was buffered and
    only appeared in blocks or not at all. The native logger also no longer
    passes the tag as a format string.
    [main.cpp]
2026-10-09 Remove the doubled newlines from log messages
    LOGI and ESP_LOGI end each message with a newline already, so the messages
    were followed by an empty line, on the device and in the emulator.
2026-10-11 Add a buffer for recording load cell samples
    Keeps the raw samples and button clicks of one recording in RAM, at most 5
    minutes, and writes them as CSV for the upload. The buffer is allocated once,
    so recording never allocates while samples come in.
    Claude-Session: https://claude.ai/code/session_01TgDoGLU2hmuEDi1yFFv2ou
2026-10-11 Replay recorded load cell samples in native tests
    RecordedScale reads a recording made on the scale and hands out its samples
    at their recorded times on the virtual clock, like SimulatedScale. A malformed
    file fails with its line number, so a broken recording can't silently test
    nothing.
    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
2026-10-11 Decide what clicks and uploads do while recording
    RecordingSession turns samples, clicks and long presses into what the recorder
    does and what its screen shows. A failed upload keeps the recording for a
    retry and stops recording until then, so the retry uploads exactly what was
    recorded. The device only passes the inputs in and does the upload, so this
    runs in native tests.
    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
2026-10-11 Receive load cell recordings on the dev server
    serve_firmware.py becomes dev_server.py. `pio run -t record` starts it in a
    recording mode: it announces record=/samples instead of the firmware path, so
    the updater's long press records instead of updating, and saves each uploaded
    recording to test/recordings. It answers only once the file is written, so the
    scale never drops a recording that wasn't saved.
    The server's tests run in CI.
    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
2026-10-11 Record load cell samples on the scale
    When the dev server found by the updater's long press is in recording mode,
    the scale records instead of updating: samples and clicks go into the
    recording, a long press uploads it as a plain HTTP POST and starts the next
    one. The CSV is measured first and then streamed, so it never needs a second
    copy in RAM.
    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
2026-10-11 Don't save recordings that arrived incomplete
    If the scale's connection broke during an upload, the server saved the part
    it got and printed it like a complete recording. The scale keeps the
    recording and uploads it again, so the partial file was a duplicate that
    looked valid. The server now rejects a body shorter than its Content-Length
    and gives up on an upload that stalls for 10 s.
    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
2026-10-11 Pin the C and C++ standards of the native builds
    The native builds use the computer's gcc. gcc 15 and newer default to C23,
    where QRCode's bool typedef doesn't compile, and gcc 16 to C++20, which
    rejects the mixed initializers in data/recipes.h. C17 and C++17 build with
    any gcc, as on CI.
2026-10-11 Don't cut off slow firmware downloads
    The 10 s timeout for stalled recording uploads also applied to the firmware
    download, and a socket timeout limits a whole write. The firmware was sent in
    one write, and the scale downloads it slower than that while writing flash, so
    every dev update stopped at about 52%. Sent in pieces, only a scale that stops
    reading is given up.
2026-10-11 Build the ESP32 firmware on every push
    Until now the firmware was only built for releases, so errors in it
    showed up at the next firmware-* tag.
2026-10-11 Add the stages of the weight pipeline, in src/weighing
    Everything between the load cell and the weight moves to src/weighing.
    A SampleSource gives the load cell's readings with the time each became
    ready, and the WeightPipeline turns each into a Reading, stage by stage:
    calibration, the same adaptive average as before (now in grams), tare,
    and the flow in grams per second over the last 2 s.
2026-10-11 Read the load cell in its own task, and hand every reading to the modes
    A task reads the HX711 as soon as its data ready interrupt fires and
    timestamps the reading. The readings wait in a queue of 32 that drops the
    oldest when full, e.g. while the updater blocks the loop.
    DefaultWeightSensor now takes all waiting readings through the weight
    pipeline on every update, and newReadings() hands them to the modes:
    espresso's estimate puts each reading at the time it was measured,
    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
2026-10-11 Keep the tare across a new calibration, and out of the first espresso point
    The tare offset is in counts again, as before the pipeline, so calibrating
    no longer leaves the weight tared with the old scale (e.g. -83700 g after
    the first calibration). A new scale starts the filter and flow over.
    Espresso skips readings from the millisecond its click tares in, which were
    made before the tare: a cup on the scale could stop the shot at once.
    Claude-Session: https://claude.ai/code/session_01S99qQA2NiWyBMgA8fuAXEU
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2026-10-11 Count the encoder in the pulse counter, and queue the button's clicks
    The encoder and the button were read by interrupts that ran all of
    Interface::update() from flash, at the same time as the loop. Quick
    turns lost detents, a click could be reset before the mode saw it, and
    an edge while the flash was written could crash the scale.
    Now the ESP32's pulse counter counts the encoder in hardware, and the
    loop turns the counts into detents, with hysteresis against bounce.
    getEncoderTurns() replaces getEncoderDirection(): it gives the detents
    since the last loop, so a quick turn counts in full in the switchers.
    A task reads the button every 5 ms and queues each click with its time.
    The loop tak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
2026-10-11 Store the settings under keys in NVS, and say when the calibration can't be read
    The calibration and the settings were stored with Arduino's EEPROM
    emulation: one blob in NVS, with a float at a fixed offset per value.
    The offset came from the enum id, so inserting or reordering a setting
    moved every stored value after it.
    Now every value has its own key in the NVS namespace "settings":
    tare0 to tare4, tareTol, avgDelta and calibration. They are stored
    through ESP-IDF's C++ NVS API instead of an Arduino library, so this
    code stays as it is when the firmware leaves Arduino. Every setter
    commits its own write, and Settings::commit() is gone.
    At the first start, the values of the old blob are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
2026-10-11 Don't let a single noisy sample end the averaging
    The averaging started over whenever two samples were more than 1 g/s apart.
    On a still scale, noise alone does that about every 12 s (σ 0.024 g per
    sample, 24 times in a 280 s recording of the empty scale), and each time the
    display showed a few unaveraged samples, up to 0.12 g off, for a second or so.
    Now, while averaging, a fast sample is held back until the next one confirms
    the change: still away from the average, measured over one sample's time. A
    spike falls back and is left out of the average; a real change, however
    small, shows one sample (~90 ms) later than before.
    Claude-Ses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
2026-10-11 Track the zero while the scale sits still, and hold it while a mode measures
    As it warms up, the empty scale drifts: +0.54 g in the first 5 minutes of a
    cold start (test/recordings/warmup.csv), which the display shows in 0.01 g
    steps. Like trade scales and other coffee scales, the pipeline now pulls the
    tared weight back to zero, but only while it is within a window around zero
    and steady (flow under 0.1 g/s), and at most 0.01 g/s, three times the
    fastest drift recorded. A 0.13 g bean lies outside the 0.1 g window and stays.
    Each mode says when it measures: espresso and the scale while their
    stopwatch runs, recipes while brewing. The zero is held then, so slow first
    drops aren't tracked awa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
2026-11-01 Record at the coffee machine, without the laptop
    Recording a shot needed the laptop next to the machine and the cup's weight
    off the display. Turning the knob now tares the recorder, as in the scale
    mode; while recording, the tare is saved as a tare row, so a replay knows
    where the shot's weight starts (RecordedScale::tares()). The samples stay
    raw.
    A long-press saves the recording to the scale's flash, with or without the
    laptop, and a long-press while idle sends all saved recordings to
    `pio run -t record`, oldest first. Each is deleted from the scale after the
    laptop answered 200; a failed send keeps the rest. The updater opens the
    recorder when it finds no server. Recordings are numbered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
